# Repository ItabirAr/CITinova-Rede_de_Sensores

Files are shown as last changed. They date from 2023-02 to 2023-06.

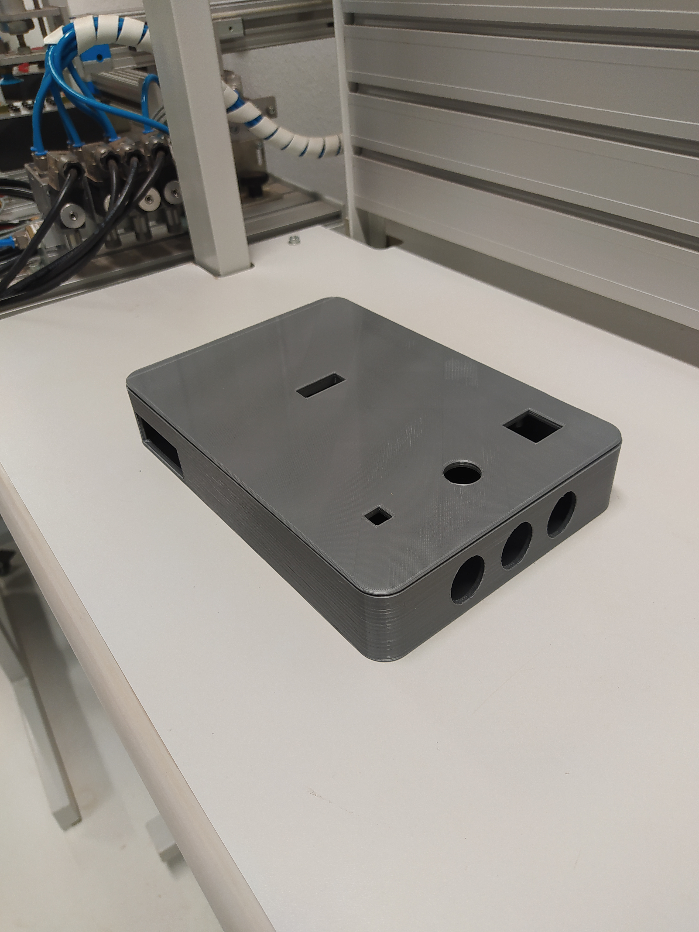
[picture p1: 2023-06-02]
CASE/Case v2/Imagens/Case_v2_impressa_5.jpg

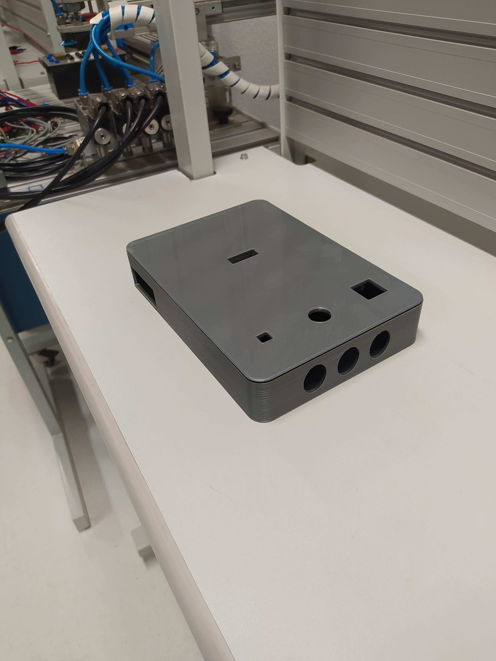
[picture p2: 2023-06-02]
CASE/Case v2/Imagens/Case_v2_impressa_4.jpg

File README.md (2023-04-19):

# Rede de sensores

O projeto Rede de sensores tem como objetivo a implementação de um protótipo capaz monitorar os principais poluentes atmosféricos de baixo custos, além de gerar um material didático que possibilite escolas e comunidades de replicar-la ou até mesmo servir de base para que possam gerar novos protótipos de monitoramento de ar.

# Monitoramento da qualidade do ar

A poluição atmosférica vem mostrando diversos impactos negativos, causando inúmeros impactos no meio ambiente (aquecimento global, degradação do meio ambiente, etc) como também está gerando graves problemas para a saúde humana.

<div align="center">

</div>

Portanto é de extrema importância o monitoramento contínuo do ar, pois são através dos dados que são criadas normas de regulamentação que colaboram para uma melhora no bem estar social e ambiental.

<div align="center">

</div>

No entanto a construção de estações de monitoramento de ar requer um alto investimento, além de a estação necessitar de manutenções rotineiras para o seu funcionamento adequado, assim gerando mais gastos.

Com isso, uma das saídas viáveis para contornar esse problema foi o uso de sensores de baixo custo.

# Sensores de baixo custo

Os sensores de baixo custo, mesmo mostrando-se inferior em relação a precisão comparados a sensores mais avançados, obtiveram êxitos em relação à eficientes para o monitoramento do ar em centros urbanos, além de demonstrar que a sua implementação é muito mais simplificada, quando comparado com modelos de monitoramentos mais avançados, além de possibilitar diversas formas flexíveis de armazenamento, sendo uma delas o armazenamento em nuvens, provando ser uma dar formas mais viáveis economicamente e extremamente eficiente para o projeto proposto, comparados a outros meios de armazenamento.

Tendo as seguintes formulações, foi se proposto no projeto, a criação de de um protótipo capaz de monitorar a qualidade do ar de baixo custo (realizando medidas de temperatura, número de partículas por milhão no ar, umidade relativa do ar, gases presentes, raios UV e etc. ) com um Arduino Uno, com armazenamento local em uma memória SD e enviadas para uma nuvem, assim possibilitando ter uma forma de armazenamento dos dados e ao mesmo tempo possibilitando o trabalho desses dados via rede.

<div align="center">

</div>

# Protótipo 

Atualmente o protótipo em desenvolvimento está sendo montado em uma protoboard, e para uma apresentação mais rápida e simplificada, foi implementado um display oled. Além dos seguintes sensores que compõem o protótipo em desenvolvimento:

<div align="center">

</div>

# Sensores 

	* MQ-135 (concentração de gases) 
	* BMP180 (Temperatura, pressão e altitude) 
	* LM35 (Temperatura)
	* UVM-30A (Raios ultravioletas) 
	* DHT11 (Temperatura e umidade relativa do ar) 
	* GY-30 (Intensidade luminosa por área) 
	* PMS5003 (Sensor de concentração de partículas)

Para mais informações em relação a cada sensor, é possível encontrar mais informações nos seguintes link: 

* <a href="https://github.com/ItabirAr/CITinova-Rede_de_Sensores/tree/main/BMP180">BMP180</a>
* <a href="https://github.com/ItabirAr/CITinova-Rede_de_Sensores/tree/main/DHT11">DHT11</a>
* <a href="https://github.com/ItabirAr/CITinova-Rede_de_Sensores/tree/main/GY30">GY30</a>
* <a href="https://github.com/ItabirAr/CITinova-Rede_de_Sensores/tree/main/LM35">LM35</a>
* <a href="https://github.com/ItabirAr/CITinova-Rede_de_Sensores/tree/main/MQ135">MQ-135</a>
* <a href="https://github.com/ItabirAr/CITinova-Rede_de_Sensores/tree/main/UVM30A">UVM-30A</a>
* <a href="https://github.com/ItabirAr/CITinova-Rede_de_Sensores/tree/main/PMS5003">PMS5003</a>

Contendo duas pastas, do qual uma delas sendo o arquivo readme.md, nela estão contidos informações básicas em relação à informações técnicas, forma de funcionamento do sensor e a forma de montagem do sensor. O outro arquivo está em um formato ino, sendo um arquivo com as programações básicas na linguagem C, para o funcionamento do sensor.

# Solicitação via Serial

A interação do protótipo Rede de Sensores com o usuário se dará via comunicação serial através do protocolo de comunicação serial RS232. O usuário poderá utilizar qualquer ferramenta que tenha essa funcionalidade, e existem várias ferramentas gratuitas disponíveis, como o PuTTY, o RealTerm e o Termite.
Além disso, é possível desenvolver uma aplicação de software dedicado para consumir as informações geradas pelo protótipo. Existem várias linguagens de programação que podem ser utilizadas para esse fim, entre elas destacam-se o Python, o Java e o C++. É importante escolher uma linguagem de programação que atenda às necessidades do projeto e que o desenvolvedor tenha conhecimento para trabalhar.

Com isso para acessar os dados armazenados na nuvem como o código elaborado e disponibilizado no projeto, existem dois comandos realizados no serial.

## getData();

No qual o comando getData() consiste em realizar uma busca completa de dados,  isto é, fazer uma impressão de todo os dados armazenados desde o seu funcionamento no serial.

<div align="center">

</div>

## getData(D1_M1_A1_D2_M2_A2)

O segundo método de impressão consiste em realizar uma busca mais específica (um intervalo de tempo mais preciso), o comando consiste em utilizar o getData(), no entanto é necessário realizar um inserção de tempo desejado, getData(D1_M1_A1_D2_M2_A2) sendo que D significa o dia, M o més e o A o ano, além de que as variáveis acompanhado com o número 1 está relacionado a data inicial de leitura e as variáveis acompanhados por 2 está relacionado a data final de leitura.

<div align="center">

</div>

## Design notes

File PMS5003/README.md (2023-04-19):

# Sensor PMS 5003

<div align="center">

</div>

Pinos   | Função | Definição
--------|--------|----------
PIN 1    | VCC    | Tensão de 5V
PIN 2    | GND    | Terra
PIN 3    | SET    | Define a tensão em 3.3V, alto nível ou suspendendo é um status normal de trabalho, enquanto baixo nível é o modo de descanso
PIN 4   | RX     | Porta serial recebendo dados / 3.3V
PIN 5   | TX     | Porta serial enviando dados / 3.3V
PIN 6   | RESET  | Reseta o sinal
PIN 7/8 | NC     |

## Descrição do Sensor
Através do espalhamento de laser dentro do cabine, há uma irradiação nas partículas presentes no interior do sensor (causando assim uma mudança nos feixes do laser em relação a condição inicial). Em seguida, tendo a alteração nos feixes do laser, os dados são coletados. Através do processamento de dados é possível obter a concentração e o tamanho das partículas no ambiente de estudo. 

<div align="center">

</div>

O PMS 5003 é um um sensor de concentração de partículas digital e universal, extremamente preciso, capaz de captar partículas de até 0.3μm. É projetado com blindagem nas 6 paredes do eletrônico para evitar interferências não desejadas. 

## Documentação

O datasheet contendo a documentação do sensor BMP180 pode ser encontrada no seguinte link: <a href="https://www.digikey.jp/htmldatasheets/production/2903006/0/0/1/pms5003-series-manual.html">Clique aqui</a>

<h1> Informações Técnicas </h1>
	
<ul>
	<li>PMS 5003</li>
	<li>Faixa de leitura de PM2,5: ±10% 100~500μ </li>
	<li>Eficiência de contagem de PM:50% para 0,3μm   98% para >=0,5μm </li>
	<li>Temperatura ideal para o funcionamento: -10 à +60°C</li>
	<li>Umidade ideal para o funcionamento: 0 à 99% de umidade relativa do ar</li>
	<li>Dimensões 50x38x21mm</li>
<ul>

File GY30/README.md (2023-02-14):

# Sensor GY30
<div align="center">

</div>

## Descrição do Sensor
Esse sensor é baseado em um semicondutor do tipo fotodiodo que, quando exposto a uma fonte de luz, absorve fótons e os converte em corrente elétrica. Portanto o sinal elétrico gerado pode ser relacionado ao nível de luminosidade do ambiente monitorado. Como o sinal gerado é muito pequeno, ele precisa ser condicionado, o que é feito através de um amplificador de sinal. Em seguida, esse sinal precisa ser preparado para ser transmitido, por isso ele passa por um conversor analógico-digital e depois por um processador que calcula o índice de luminosidade com base na quantidade de luz absorvida. Por fim, o índice de luminosidade é transmitido para ser armazenado.

<div align="center">

</div>

O sensor, fabricado por ROHM Semiconductor, foi projetado para detectar o espectro de luz visível ao olho humano com sensibilidade de pico em 560 nm, que está no espectro verde. Agama completa abrange aproximadamente 400 nm a 700 nm. O sensor funciona bem com amaioria das luzes brancas visíveis, incluindo a luz solar, incandescente, fluorescente, halógena e LED branca. Tem boa rejeição de UV e IR.
O I2C utiliza dois canais para comunicação. A diferença é que, nesse caso, um canal é de transmissão e recepção de dados e outro é para sincronização dos mesmos. Em relação aos dois canais de comunicação, temos: o canal de dados seriais, chamado de serial data (SDA); e o canal de sincronização, chamado serial clock (SCL). Simplificadamente, o Clock é um sinal que oscila entre nível alto e baixo rapidamente. Então, essa oscilação é utilizada para sincronizar os dispositivos a cada vez que o clock apresentar certo estado.

## Documentação

O datasheet contendo a documentação do sensor BMP180 pode ser encontrada no seguinte link: <a href="https://www.mouser.com/datasheet/2/348/bh1750fvi-e-186247.pdf">Clique aqui</a>

<h1> Informações Técnicas </h1>
	
<ul>
	<li>Tensão de operação 3 à 5VDC</li>
	<li>Faixa de leitura de luminosidade: 1 à 65535lx(±20%)</li>
	<li>Conexão I2C</li>
	<li>Dimensões 33x20x3mm</li>
<ul>

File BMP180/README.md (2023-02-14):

# Sensor BMP180

<div align="center">

</div>

## Descrição do Sensor
O BMP180 é composto por um sensor piezoresistivo e um sensor MEMS de temperatura. 
O sensor piezoresistivo utiliza um diafragma de material semicondutor cuja resistência varia de acordo com a pressão. Dessa forma, a intensidade da corrente que passa pelo diafragma é proporcional à força causada pela pressão. 
O sensor de temperatura é um MEMS (Sistema Microeletromecânico) que funciona a partir de uma lente de silício que reúne a radiação infravermelha em um material semicondutor cuja informação de temperatura está correlacionada com a diminuição da resistência do material. 

<div align="center">

</div>

O BMP180 mede temperatura, altitude e pressão. Porém para esse projeto serão coletados apenas os dados de temperatura e pressão fornecidos pelo sensor. O modelo é fabricado pela BOSCH Invented For Life, ou pela TEXAS INSTRUMENTS.
Utiliza-se a Comunicação Serial I2C – Inter-Integrated Circuit – a qual utiliza dois canais para comunicação: um canal para transmissão e recepção de dados (SDA) e outro a para sincronização dos dados (SCL).

## Documentação

O datasheet contendo a documentação do sensor BMP180 pode ser encontrada no seguinte link: <a href="https://cdn-shop.adafruit.com/datasheets/BST-BMP180-DS000-09.pdf">Clique aqui</a>

<h1> Informações Técnicas </h1>
	
<ul>
	<li>CI BMP180</li>
	<li>Tensão de operação 1.8 à 3.6VDC</li>
	<li>Consumo de corrente: 0.5µA</li>
	<li>Faixa de leitura de pressão: 300 à 11001hPa(+9000 à -500m)</li>
	<li>Conexão I2C</li>
	<li>Sensor de temperatura embutido: -40 à +85°C</li>
	<li>Calibrção de fábrica</li>
	<li>Dimensões 13x10mm</li>
<ul>

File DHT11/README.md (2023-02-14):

# Sensor DHT11

<div align="center">

</div>

## Descrição do Sensor
O DHT11 é composto por um sensor resistivo e um termistor NTC. 
O sensor resistivo mede a umidade pela variação da resistência de um material capaz de absorver umidade. Ao absorver vapor d‘água, a resistência do material diminui por causa do aumento da condutividade elétrica. 
Um termistor é um dispositivo elétrico cuja resistência elétrica altera drasticamente com a temperatura. Para o tipo NTC, a resistência interna reduz com o aumento da temperatura, geralmente utiliza-se uma Ponte de Wheatstone ou um Amplificador para obter uma aproximação linear. 

<div align="center">

</div>

O DH11 realiza medições de temperatura (°C) e umidade relativa do ar (%UR). Os principais fabricantes são a  UNIVERSAL-SOLDER Electronics Ltd  e a  Guangzhou Aosong Electronics Co Ltd . O sensor deve ser alimentado por fonte de tensão entre 3,0V e 5,5V.
O DTH11 transmite dados por comunicação serial Single-Wire Two-Way, o sensor possui conversor análogo digital interno de 16 bits. Após o microcontrolador enviar um sinal de inicialização, o sensor entra em modo de execução. É transmitido um sinal de 40 bits para o Arduino, em pacotes de 8 bits: o byte. Os primeiros 4 bytes são as informações de umidade e temperatura. O último byte trata-se da soma dos 32 dígitos anteriores, para verificação de autenticidade dos dados. Em seguida, o sensor entra em modo de baixo consumo e aguarda um novo sinal do Arduino.

## Documentação

O datasheet contendo a documentação do sensor DHT11 pode ser encontrada no seguinte link: <a href="https://www.mouser.com/datasheet/2/758/DHT11-Technical-Data-Sheet-Translated-Version-1143054.pdf">Clique aqui</a>

<h1> Informações Técnicas </h1>
	
<ul>
	<li>Tensão de operação 3 à 5.5VDC</li>
	<li>Consumo de corrente: 0.5 à 2.5µA</li>
	<li>Faixa de leitura de umidade: 20 à 90% (±5%) RH</li>
	<li>Faixa de leitura de temperatura: 0° à 50° (±2°) C</li>
	<li>Saída: Digital</li>
	<li>Dimensões 12x23.5x5.5mm</li>
<ul>

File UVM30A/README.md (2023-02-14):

# Sensor UVM-30A

O sensor UVM30A é utilizado para medir a intensidade de radiação ultravioleta. O codigo disponivel esta normalizado para ter como resultado a intensidade UV de acordo com o index UV, padrão internacional de medida da intensidade UV.

<div align="center">

</div>

## Descrição do Sensor
O funcionamento interno do módulo UVM30A é baseado em um fotodiodo, que é o componente responsável por converter a radiação Ultra Violeta em corrente elétrica. A luz UV incide no fotodiodo, causando a liberação de elétrons e a criação de portadores de carga geram uma corrente elétrica proporcional à intensidade da radiação UV.
A corrente gerada pelo fotodiodo é amplificada por um circuito amplificador operacional e processado por um circuito de compensação de temperatura, que corrige as variações da sensibilidade do fotodiodo com a temperatura. O circuito completo é encapsulado em uma caixa para protegê-lo contra a radiação UV e outros ambientes adversos.

<div align="center">

</div>

O UVM30A mede a intensidade de incidência dos raios ultravioletas e é fabricado pela EKT.
Através da porta analógica, o sensor é alimentado com uma tensão de operação e no terceiro terminal, sai uma tensão proporcional à incidência de luz UV.     A radiação ultravioleta (UV) é entendida como toda a radiação eletromagnética com comprimento de onda entre 200 e 400 nanômetros (nm), sendo assim o sensor emite um sinal elétrico que varia com a intensidade UV, ou seja, de acordo com o comprimento da onda.

## Documentação

O datasheet contendo a documentação do sensor UVM-30a pode ser encontrada no seguinte link: <a href="https://www.google.com/url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">Clique aqui</a>

Este sensor não necessita de nenhuma biblioteca para seu funcionamento.

## Informações Técnicas
	
<ul>
	<li>Tensão de operação: 3 à 5VDC</li>
	<li>Consumo de corrente: 0.06 à 0.1µA</li>
	<li>Tensão de saída: 0-1V (correspondente a 0-10 UV index)</li>
	<li>Leitura de onda UV na faixa de 200 à 37-nm</li>
	<li>Temperatura de trabalho: -20° à +85°C</li>
	<li>Dimensões 28x12x10mm</li>
<ul>

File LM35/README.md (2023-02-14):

# Sensor LM35

O LM35 é um sensor de temperatura linear de baixo custo, que fornece uma saída de tensão proporcional à temperatura. Ele é amplamente utilizado em sistemas de controle de temperatura devido à sua facilidade de uso e precisão.
<div align="center">

</div>

## Descrição do Sensor
O LM35 é composto por um elemento termoelétrico, geralmente feito de silício, protegido por uma caixa metálica, que também funciona como um terminal de referência para a medição de tensão. Usa o princípio básico de um diodo, onde à medida que a temperatura aumenta em comparação com a temperatura de referência, a tensão através de um diodo aumenta a uma taxa conhecida (10mV/°C). Ao amplificar precisamente a mudança de tensão, gera um sinal analógico diretamente proporcional à diferença de temperatura.

<div align="center">

</div>

O LM35 mede temperatura ambiente e é fabricado pela TEXAS INSTRUMENTS.
Comunica-se por Porta Serial Analógica, que entrega uma tensão proporcional a temperatura, ademais há outros 2 pinos no sensor, estes de alimentação Vcc e GND

## Documentação

O datasheet contendo a documentação do sensor LM35 pode ser encontrada no seguinte link: <a href="https://www.google.com/url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">Clique aqui</a>

Este sensor nao necessita de biblioteca para seu funcionamento 

<h2> Informações Técnicas </h2>
	
<ul>
	<li>Tensão de operação 4 à 30VDC</li>
	<li>Consumo de corrente máxima: 60µA</li>
	<li>Faixa de leitura de temperatura: -55° à 150° (±0.5°) C</li>
<ul>

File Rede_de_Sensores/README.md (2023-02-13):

# Integração dos Sensores

<div align="center">

</div>

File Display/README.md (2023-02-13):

# Display

O display OLED SSD1306 é um tipo de display de cristal líquido orgânico de alta qualidade, que é utilizado em muitos projetos de eletrônica e robótica. É caracterizado por sua alta resolução, baixo consumo de energia e excelente contraste, tornando-o uma escolha popular para aplicações de visualização de dados.

<div align="center">

</div>

## Descrição do display

O SSD1306 é controlado por um controlador de display OLED integrado, que é responsável por gerenciar todas as operações de exibição, incluindo a renderização de texto e gráficos. O display é alimentado por meio de uma conexão serial I2C, e pode ser facilmente integrado a microcontroladores como o Arduino, Raspberry Pi ou outros dispositivos similares.

O SSD1306 é altamente personalizável, permitindo aos usuários definir o tamanho e o formato da tela, bem como ajustar as configurações de contraste, brilho e outras opções de visualização. Além disso, ele suporta a exibição de texto e gráficos, incluindo fontes personalizadas, gráficos vetoriais e imagens bitmap.

## Documentação

O datasheet contendo a documentação do display pode ser encontrado no seguinte link: <a href="https://datasheethub.com/wp-content/uploads/2022/08/SSD1306.pdf">Clique aqui</a> 

Para ter acesso as configurações de personalização do display é utilizada as seguintes bibliotecas:
<ul>
	<li>Adafruit_SSD1306 disponivel em:  <a href="https://www.arduinolibraries.info/libraries/adafruit-ssd1306">Clique aqui</a> </li>
	<li>Adafruit_GFX disponivel em: <a href="https://www.arduinolibraries.info/libraries/adafruit-gfx-library">Clique aqui</a> </li>
<ul>

## Informações tecnicas
  
<ul>
	<li>Tamanho da tela: 0.96 polegadas</li>
	<li>Resolução: 128x64 pixels</li>
	<li>Interface de comunicação I2C</li>
	<li>Alimentação: Vdc de 3.3V á 5V e consome cerca de 60mA em operação</li>
<ul>

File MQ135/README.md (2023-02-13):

# Sensor MQ-135

O sensor MQ135 será utilizado para medir a concentração de gás CO2. Este sensor é projetado especificamente para detectar gases poluentes, como dióxido de carbono, e fornecer uma leitura precisa da concentração de gás no ar. 

<div align="center">

</div>

## Descrição do Sensor
Trata-se de um sensor semicondutor do tipo MOS (metal oxide semiconductor). O material sensível do sensor é o SnO2 (óxido de estanho), que possui baixa condutividade quando exposta ao ar limpo. À medida que surgem algum tipos de gases, sua condutividade aumenta com a concentração desses gases. Colocando-se então esse material entre dois eletrodos e em série com uma resistência conhecida e, aplicando-se uma tensão elétrica constante sobre esse conjunto, obtém-se na saída uma tensão elétrica proporcional à concentração de gases. Quanto maior a concentração de gás, maior será a tensão de saída. O sensor tem uma temperatura de funcionamento padrão que é fornecida por um eletrodo de aquecimento

<div align="center">

</div>

O sensor MQ-135 é capaz de detectar gases tóxicos no ar, podendo detectar concentrações entre 10 e 300 ppm (partes por milhão) de amônia e álcool e entre 10 e 1000 ppm de benzeno no ar. A sua sensibilidade é ajustada por um trimpot acoplado a sua placa. Em concentrações normais do gás, a saída digital do sensor permanece desligada, quando o ponto de ajuste (setpoint) é ultrapassado, a saída digital é ligada permanecendo em nível alto. Além da saída digital, o sensor possui saída analógica, possibilitando a leitura da concentração medida de gases no ar com precisão. Sempre que alimentado, o LED de alimentação permanecerá aceso, já o LED da saída digital é acionado quando o valor lido pelo sensor superar o ponto de ajuste. O trimpot é o variador da sensibilidade na qual aciona a saída digital.

## Documentação
O datasheet contendo a documentação do sensor MQ-135 pode ser encontrado no seguinte link: <a href="https://pdf1.alldatasheet.com/datasheet-pdf/view/1307647/WINSEN/MQ135.html">Clique aqui</a> 

Para o sensor medir concentrações de CO2 é importante atentar a algumas configurações que devem ser realizadas previamente, as informações e procedimentos pode ser encontrados no seguinte link: <a href="https://circuitdigest.com/microcontroller-projects/interfacing-mq135-gas-sensor-with-arduino-to-measure-co2-levels-in-ppm">Clique aqui</a> 

A biblioteca utilizada no código pode ser encontrada no seguinte link: <a href="https://www.arduinolibraries.info/libraries/mq135">Clique aqui</a> 

## Informações tecnicas
<ul>
	<li>Tensão de operação: 5VDC</li>
	<li>Faixa de detecção amônia: 10ppm à 300ppm</li>
	<li>Faixa de detecção benzeno: 10ppm à 1000ppm</li>
	<li>Faixa de detecção álcool: 10ppm à 300ppm</li>
	<li>Saídas: Digital e analógica</li>
	<li>Dimensões 40x25x22mm</li>
<ul>

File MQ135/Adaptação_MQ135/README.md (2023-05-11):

# MQ-135

Inicialmente o sensor MQ-135 foi projetado para detectar uma alta variedade de gases nocivos (NH3, NOx, álcool, benzeno, fumaça e CO2). No entanto, para atender aos interesses do projeto, foram feitas adaptações para que o sensor leia apenas quantidades de CO2 presente no ar.

Sabendo-se que os valores lidos pelo sensor é uma conversão do valor lido na tensão entregue na carga resistiva, sendo que a variação da tensão depende do valor da carga resistiva presente no sensor. É de extrema importância que a resistência presente no sensor tenha um valor expressivo para que o cálculo na leitura possa ser preciso.

# Procedimento

Inicialmente para iniciar a adaptação do sensor MQ-135 para a leitura de CO2, é necessário a troca do resistor  Rs de 1K ohm para uma resistência de 22k ohm, pois a leitura de CO2 é mais sensível que outros gases, resultando em uma variação de tensão menor caso o Rs seja um valor muito baixo.

<div align="center">

</div>

Fazendo se a troca é possível observar com uma maior variação, pois a tensão lida é feita através do cálculo da divisão de tensão entre Rs e a resistência lida no material SnO2.

Tendo feita a seguinte troca, o restante das adaptações a partir serão as mudanças feitas através de softwares. Os dados necessários para as alterações inicialmente e descobrir o valor da resistência resultante do material SnO2 em ar limpo. Para medir tais valores inicialmente é necessário manter o sensor ligado durante um período de 24 horas e após isso utiliza-se o seguinte código, o código retornará um valor para o R0 no serial.

```
#include "MQ135.h"
configuração nula (){
Serial.begin (9600);
}
loop void() {
Sensor de gás MQ135 = MQ135(A0); // Conecta o sensor ao pino A0
float rzero = gasSensor.getRZero();
Serial.println (rzero);
atraso(1000);
}
```
Tendo o valor medido, é preciso atualizar os dados da biblioteca, e para isso basta seguir o seguinte caminho: Documentos > Arduino > bibliotecas > pasta MQ135 e abra o arquivo MQ135.h e altere os valores RLOAD e RZERO.

<div align="center">

</div>

obs: atualizar também o valor de ATMOCO2, que é um valor médio de CO2 presente na atmosfera terrestre, um valor que pode ser encontrado na internet (Para julho de 2022 foi encontrado um valor de 414.47).

<div align="center">

</div>

# Referência

Measuring CO2 concentration in air using Arduino and MQ-135 sensor. Disponível em: <https://circuitdigest.com/microcontroller-projects/interfacing-mq135-gas-sensor-with-arduino-to-measure-co2-levels-in-ppm>. Acesso em: 30 abr. 2023.

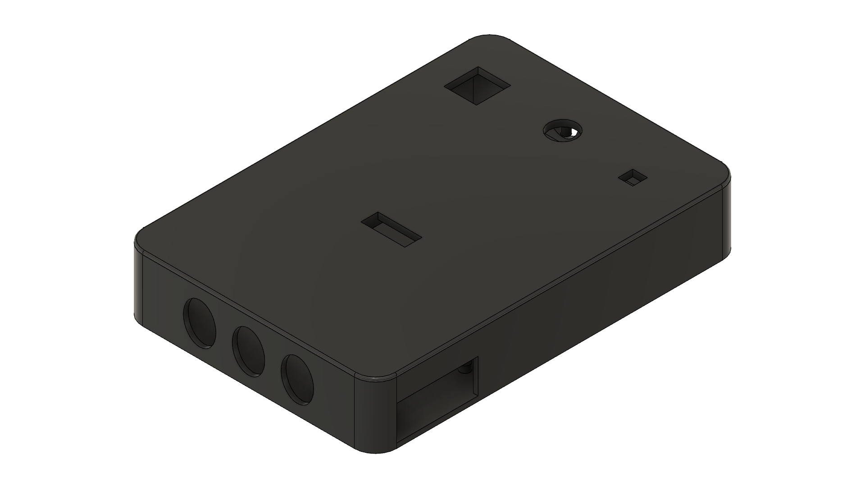
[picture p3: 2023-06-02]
CASE/Case v2/Imagens/Case_v2_fechada_sem_renderizar.png

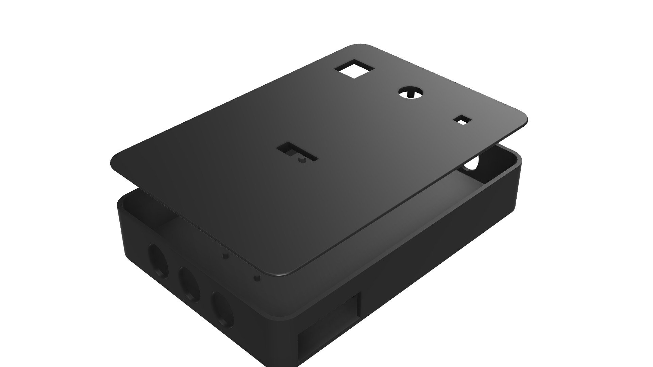
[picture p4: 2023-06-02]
CASE/Case v2/Imagens/Case_v2_aberta.png

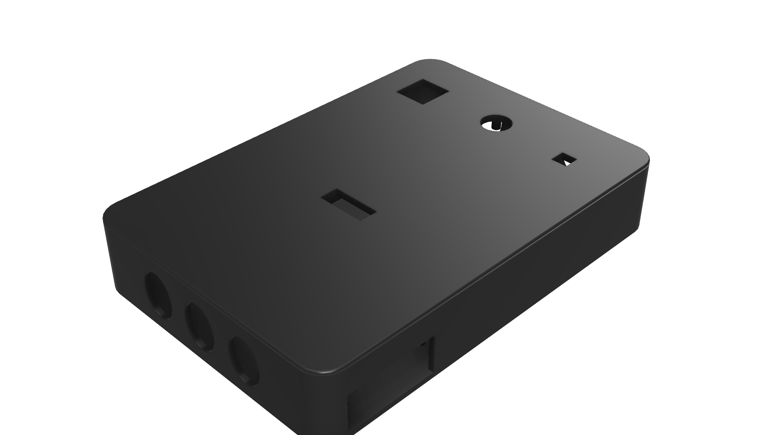
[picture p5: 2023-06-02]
CASE/Case v2/Imagens/Case_v2_fechada.png

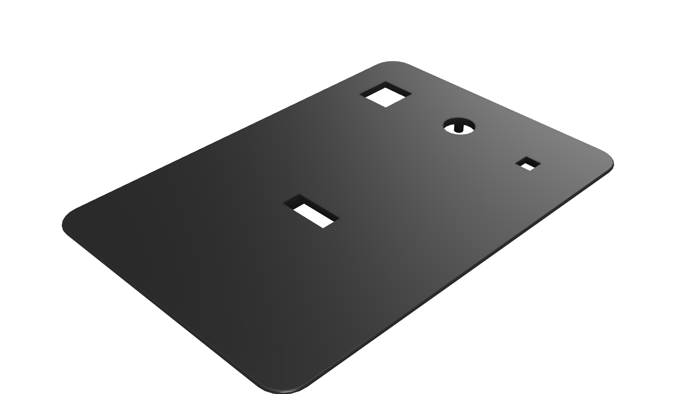
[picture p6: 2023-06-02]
CASE/Case v2/Imagens/Case_v2_tampa.png

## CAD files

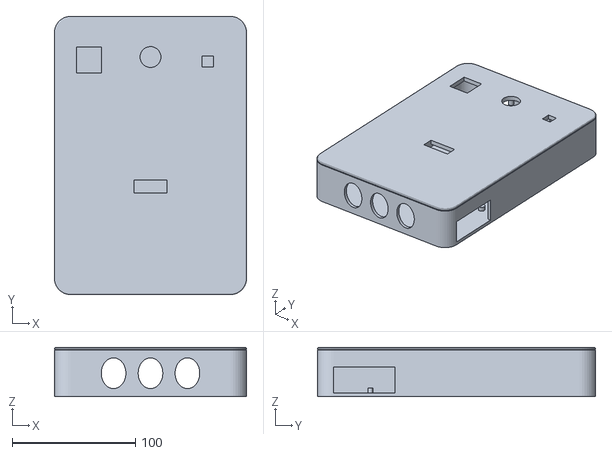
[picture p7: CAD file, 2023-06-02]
CASE/Case v2/Modelagem/Case_v2.stl
156.0 x 226.0 x 40.0

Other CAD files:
CASE/Case v1/Modelagem/Case_V1.f3d
CASE/Case v2/Modelagem/Case_v2.f3d

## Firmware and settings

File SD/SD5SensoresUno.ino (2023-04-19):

// Integração Módulo SD com BMP180, MQ135, UVM30A, DHT11, GY30
#include <SD.h> // Biblioteca para comunicação com cartão SD
#include <Adafruit_BMP085.h> //biblioteca do sensor BMP180
#include <MQ135.h> //biblioteca do sensor MQ135
#include <DHT.h> //biblioteca do sensor DHT11
#include <Wire.h> // bibilioteca de comunicação entre dispositivos por protocolo I2C
#include <BH1750.h> //biblioteca do sensor GY30

File dataFile; // Objeto que representa o arquivo de dados
const int chipSelect = 10; // Pino para seleção do cartão SD
unsigned long lastSaveTime = 0; // Último momento em que os dados foram salvos no cartão SD
unsigned long lastReadTime = 0; // Último momento em que os sensores foram lidos
String fileName = "bmp.txt";; // Nome do arquivo
char valueSerial;

// Buffers para armazenamento de dados
int bufferIndex = 0; // Índice atual do buffer
const int bufferSize = 10; // Tamanho do buffer de dados
String dataString = ""; // Cria uma string
// BMP180 (5V) SDA, SCL
Adafruit_BMP085 bmp; // define bmp como objeto do tipo Adafruit_BMP085 (I2C)
float bufferTemperaturaBMP[bufferSize]; // vetor para os dados lidos de temperatura
int bufferPressaoBMP[bufferSize]; // vetor para os dados lidos de pressão

long int Millis[bufferSize];


// MQ135 (5V) A2
#define pinoMQ A2
MQ135 mq = MQ135(pinoMQ);
float bufferCo2MQ[bufferSize]; // vetor para os dados lidos de CO2
// UVM30A (5V) A0
#define pinoUVM A0
int bufferUltravioletaUVM[bufferSize];   // declara um vetor para a resposta do sensor
// DHT11 (5V) A1
#define pinoDHT A1 // pino usado para conexão
#define modeloDHT DHT11 // modelo do sensor
DHT dht(pinoDHT, modeloDHT); // define dht como objeto do tipo DHT
float bufferTemperaturaDHT[bufferSize]; // vetor para os dados lidos de temperatura
float bufferUmidadeDHT[bufferSize]; // vetor para os dados lidos de umidade
// GY30 (5V) SDA, SLC
BH1750 gy; // define gy como objeto do tipo BH1750
float bufferIluminanciaGY[bufferSize]; // vetor para os dados lidos de iluminãncia (intensidade luminosa por área) 

void setup() {
  // Inicia comunicação serial com taxa de 9600 bps
  Serial.begin(9600); 
  Serial.println("Inicializando componentes...");
  
  // Configura pino de seleção do cartão SD como saída
  pinMode(chipSelect, OUTPUT);
  SD.begin(chipSelect);
  /* Inicializa cartão SD
  if (!SD.begin(chipSelect)) {
    Serial.println("Erro ao inicializar o cartão SD! Verifique as conexões.");
    return;
  }*/
  
  // Inicialização do BMP180
  if (!bmp.begin()) { 
    // se o sensor não for inicializado, apresenta a mensagem:
    Serial.println("Sensor BMP180 não foi identificado! Verifique as conexões.");
    while (1) {
      // em loop (repetições) até o sensor inicializar
    }
  }
  // Inicialização do DHT11
  dht.begin(); //inicializa o sensor DHT11
  // Inicialização do GY30
  Wire.begin(); //inicializa o I2C BUS
  gy.begin(); //inicializa o sensor GY30
  // Testa se os sensores DHT11 e GY30 estão recebendo dados numéricos
  testeDHT_GY();
  
  // Deleta um arquivo de mesmo nome caso já exista
  if(SD.exists(fileName)) {
    SD.remove(fileName);
  }
  // Cria arquivo de dados
  if (!SD.exists(fileName)) {
    dataFile = SD.open(fileName, FILE_WRITE);
    dataFile.close();
  }
  
  // Abre o arquivo e escreve legenda dos dados
  dataFile = SD.open(fileName, FILE_WRITE);
  dataString = "Tempo[ms], Conc.CO2[ppm], IndiceUV, Temperatura[°C], UmidadeRelativa[%UR], Iluminância[lux]";
  dataFile.print(dataString);
  dataFile.close();
  
  lastSaveTime = millis(); // Inicializa variável de último momento de salvamento de dados
  
 
  // Inicializa buffers de dados com valor 0
  for (int i = 0; i < bufferSize; i++) {
    Millis[i] = 0;
    bufferTemperaturaBMP[i] = 0;
    bufferPressaoBMP[i] = 0;
    bufferCo2MQ[i] = 0;
    bufferUltravioletaUVM[i] = 0;
    bufferTemperaturaDHT[i] = 0;
    bufferUmidadeDHT[i] = 0;
    bufferIluminanciaGY[i] = 0;
  }
  
  Serial.println("Programa iniciado."); // Imprime mensagem de início do programa
}


void loop() {
  unsigned long currentTime = millis(); // Obtém momento atual

  // Realiza leitura dos sensores a cada 1 segundo
  if (currentTime - lastReadTime >= 1000) {
    Millis[bufferIndex]=millis();
    
    bufferTemperaturaBMP[bufferIndex] = bmp.readTemperature(); // temperatura informada pelo sensor
    bufferPressaoBMP[bufferIndex] = bmp.readPressure(); // pressão informada pelo sensor
    bufferCo2MQ[bufferIndex] = mq.getPPM(); // concentração de CO2 informada pelo sensor
    bufferUltravioletaUVM[bufferIndex] = medicaoUVM(); // atribui o valor do índice de radiação uv por meio de uma função
    bufferTemperaturaDHT[bufferIndex] = dht.readTemperature();  // temperatura informada pelo sensor
    bufferUmidadeDHT[bufferIndex] = dht.readHumidity(); // umidade informada pelo sensor
    bufferIluminanciaGY[bufferIndex] = gy.readLightLevel(); // iluminância informada pelo sensor
    bufferIndex++; // Incrementa índice do buffer

    // Salva dados no cartão SD quando o buffer estiver cheio
    if (bufferIndex == bufferSize) {
        Serial.println("Tempo[ms], Temp_BMP180[°C], Pressao[Pa], Conc.CO2_MQ135[ppm], Temp_LM35[°C], IndiceUV, Temp_DHT11[°C], UmidadeRelelativa[%UR], Iluminância[lux]");
      monitorSerial();
      saveData();
      testeDHT_GY();
      bufferIndex = 0;
    }

    // Atualiza último momento de leitura dos sensores
    lastReadTime = currentTime;
  }
  if (Serial.available()) { //verifica se entrou com requisição de dados no serial
    valueSerial = Serial.read();
    if(valueSerial == '1'){ //comando 1 retorna todos os dados
      requisicaoGetData();
   }
    if(valueSerial == '2'){  // comando 2 retorna dados de um intervalo
      requisicaoGetInterval();
    }
  }
}

// Função do UVM30A
int medicaoUVM(){
  float leituraSensorUVM = analogRead(pinoUVM)*(5000 / 1023); // atribui nível de tensão de saída do sensor a uma variavel
  if (leituraSensorUVM >= 0 && leituraSensorUVM < 50) {
    return 0;
  } else if (leituraSensorUVM >= 50 && leituraSensorUVM < 227) {
    return 1;
  } else if (leituraSensorUVM >= 227 && leituraSensorUVM < 318) {
    return 2;
  } else if (leituraSensorUVM >= 318 && leituraSensorUVM < 408) {
    return 3;
  } else if (leituraSensorUVM >= 408 && leituraSensorUVM < 503) {
    return 4;
  } else if (leituraSensorUVM >= 503 && leituraSensorUVM < 606) {
    return 5;
  } else if (leituraSensorUVM >= 606 && leituraSensorUVM < 698) {
    return 6;
  } else if (leituraSensorUVM >= 698 && leituraSensorUVM < 795) {
    return 7;
  } else if (leituraSensorUVM >= 795 && leituraSensorUVM < 881) {
    return 8;
  } else if (leituraSensorUVM >= 881 && leituraSensorUVM < 976) {
    return 9;
  } else if (leituraSensorUVM <= 976 && leituraSensorUVM < 1079) {
    return 10;
  } else if (leituraSensorUVM > 1079) {
    return 11;
  }
}



void testeDHT_GY() {
  float temperaturaDHT = dht.readTemperature();  // temperatura informada pelo sensor
  float umidadeDHT = dht.readHumidity(); // umidade informada pelo sensor
  if (isnan(temperaturaDHT) || isnan(umidadeDHT)) { 
    //se a for atribuido um valor não numérico, indica erro de leitura no DHT11
    Serial.println("Falha de leitura do DHT11! Verifique as conexões.");
  }
  float iluminanciaGY = gy.readLightLevel(); // iluminância informada pelo sensor
  if (isnan(iluminanciaGY)) { 
    //se a for atribuido um valor não numérico, indica erro de leitura no GY30
    Serial.println("Falha de leitura do GY30! Verifique as conexões.");
  }
}



void saveData() {
  // Obtém momento atual
  unsigned long currentTime = millis();

  // Verifica se já passaram 10 segundos desde o último salvamento de dados
  if (currentTime - lastSaveTime < 10000) {
    return;
  }

  // Atualiza o lastSaveTime com o currentTime
  lastSaveTime = currentTime;

  // Atribui os dados do buffer
  for (int i = 0; i < bufferSize; i++) {
    dataString += String(currentTime - ((bufferSize - 1 - i) * 1000)) + ", ";  
    dataString += String(bufferTemperaturaBMP[i]) + ", ";
    dataString += String(bufferPressaoBMP[i]) + ", ";
    dataString += String(bufferCo2MQ[i]) + ", ";
    dataString += String(bufferUltravioletaUVM[i]) + ", ";
    dataString += String(bufferTemperaturaDHT[i]) + ", ";
    dataString += String(bufferUmidadeDHT[i]) + ", ";
    dataString += String(bufferIluminanciaGY[i]) + "\n";
  }

  // Abre o arquivo para escrita e escreve os dados
  dataFile = SD.open(fileName, FILE_WRITE);
  dataFile.print(dataString);
  dataFile.close();

  Serial.println("Dados salvos.");
}

//Função de requisição de todos os dados do sd
void requisicaoGetData(){
  dataFile = SD.open("BMP.txt");
  if(dataFile){
    while(dataFile.available()){
      Serial.write(dataFile.read());
    }
  }
}

//requisição de um intervalo de dados do SD
void requisicaoGetInterval(){
  unsigned long start_time = Serial.parseInt();
  unsigned long end_time = Serial.parseInt();
  Serial.print("Tempo inicial: ");
  Serial.println(start_time);
  Serial.print("Tempo final: ");
  Serial.println(end_time);

  dataFile = SD.open("BMP.txt");
  if(dataFile){
    while(dataFile.available()){
      String request = dataFile.readStringUntil('\n');
      String timeStr = request.substring(0, request.indexOf(','));
      unsigned long time = timeStr.toInt();
      if (time >= start_time && time <= end_time) {
        String valueStr = request.substring(request.indexOf(',') + 1);
        Serial.print("Tempo: ");
        Serial.print(time);
        Serial.print(" | Valor: ");
        Serial.println(valueStr);
      }
    }
  }
}

// ** MONITOR SERIAL **
void monitorSerial() { // função para imprimir  os resultados obtidos
  for(int j = 0; j < bufferSize; j++) {
    
    Serial.print(Millis[j]); //BMP180
    Serial.print(", ");
    Serial.print(bufferTemperaturaBMP[j]); //BMP180
    Serial.print(", ");
    Serial.print(bufferPressaoBMP[j]);   
    Serial.print(", ");
    Serial.print(bufferCo2MQ[j]); //MQ135   
    Serial.print(", ");
    Serial.print(bufferUltravioletaUVM[j]); //UVM3OA   
    Serial.print(", ");
    Serial.print(bufferTemperaturaDHT[j]); //DHT11
    Serial.print(", ");
    Serial.print(bufferUmidadeDHT[j]);   
    Serial.print(", ");
    Serial.println(bufferIluminanciaGY[j]); //GY30
  }
}

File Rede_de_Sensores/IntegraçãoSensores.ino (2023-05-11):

// Integração dos sensores BMP180, MQ135, LM35, UVM30A, DHT11, GY30 com interrupção
#include <TimerOne.h> //biblioteca do temporizador interno do arduino
#include <Adafruit_BMP085.h> //biblioteca do sensor BMP180
#include <MQ135.h> //biblioteca do sensor MQ135
#include <DHT.h> //biblioteca do sensor DHT11
#include <Wire.h> //bibilioteca de comunicação entre dispositivos por protocolo I2C
#include <BH1750.h> //biblioteca do sensor GY30

bool flag = false; // variável auxiliar para indicar a contagem de tempo
int p = 0; // variável auxiliar de posição dos vetores
const int tamanhoBuffer = 10; // tamanho do vetor
long bufferTempo[tamanhoBuffer]; // vetor com os dados de tempo

// ** VARIAVEIS BMP180 ** (3,3V) SDA-A4, SCL-A5
Adafruit_BMP085 bmp; // define bmp como objeto do tipo Adafruit_BMP085 (I2C)
float bufferTemperaturaBMP[tamanhoBuffer]; // vetor para os dados lidos de temperatura
int bufferPressaoBMP[tamanhoBuffer]; // vetor para os dados lidos de pressão

// ** VARIAVEIS MQ135 ** (5V) A0 
#define pinoMQ A2
MQ135 mq = MQ135(pinoMQ);
float bufferCo2MQ[tamanhoBuffer]; // vetor para os dados lidos de CO2

// ** VARIAVEIS LM35 ** (5V) A2
#define pinoLM A4
float bufferTemperaturaLM[tamanhoBuffer];  //declara um vetor para resposta do sensor

// ** VARIAVEIS UVM30A ** (3,3V ou 5V) A1
#define pinoUVM A0
int bufferUltravioletaUVM[tamanhoBuffer];   // declara um vetor para a resposta do sensor

// ** VARIAVEIS DHT11 ** (3,3V ou 5V) A3
#define pinoDHT A1 // pino usado para conexão
#define modeloDHT DHT11 // modelo do sensor
DHT dht(pinoDHT, modeloDHT); // define dht como objeto do tipo DHT
float bufferTemperaturaDHT[tamanhoBuffer]; // vetor para os dados lidos de temperatura
float bufferUmidadeDHT[tamanhoBuffer]; // vetor para os dados lidos de umidade

// ** VARIAVEIS GY30 ** (3,3V ou 5V) SDA, SLC
BH1750 gy; // define gy como objeto do tipo BH1750
float bufferIluminanciaGY[tamanhoBuffer]; // vetor para os dados lidos de iluminãncia (intensidade luminosa por área) 

void setup() {
// inicializa monitor serial
  Serial.begin(9600); 
// ** INICIALIZA BMP180 **
  if (!bmp.begin()) { 
    //se o sensor não for inicializado, apresenta a mensagem:
    Serial.println("Sensor BMP180 não foi identificado! Verifique as conexões.");
    while (1) {  //em loop (repetições) até o sensor inicializar
    } 
  }
// ** INICIALIZA DHT11 **
  dht.begin(); //inicializa o sensor DHT11
// ** INICIALIZA GY30 **
  gy.begin(); //inicializa o sensor GY30
// temporizador interno do arduino
  Timer1.initialize(1000000); // 1s
  Timer1.attachInterrupt(callback);
// *** variáveis medidas e unidades (lux = lm/m²)
  Serial.println("Tempo[ms], Temp_BMP180[°C], Pressao[Pa], Conc.CO2_MQ135[ppm], Temp_LM35[°C], IndiceUV, Temp_DHT11[°C], UmidadeRelelativa[%UR], Iluminância[lux]");
}

void callback(){
  flag = true;
}

void loop(){   
  if(flag){
    bufferTempo[p] = millis(); // milissegundos transcorridos desde que o Arduino foi ligado
    medicaoBMP();
    medicaoMQ();
    medicaoTemperaturaLM();
    bufferUltravioletaUVM[p] = medicaoUVM(); // atribui o valor do índice de radiação uv
    medicaoDHT();
    medicaoGY();
    p++;
    if (p == tamanhoBuffer-1) {
      monitorSerial(); // função que mostra os dados salvos nos vetores
      p = 0; // retorna à posição inicial dos vetores para salvar novos dados
    }
    flag = false;
  }
}



// ** FUNÇÃO BMP180 **
void medicaoBMP() {
  bufferTemperaturaBMP[p] = bmp.readTemperature(); // temperatura informada pelo sensor
  bufferPressaoBMP[p] = bmp.readPressure(); // pressão informada pelo sensor
}

// ** FUNÇÃO MQ135 **
void medicaoMQ(){     
  bufferCo2MQ[p] = mq.getPPM(); // concentração de CO2 informada pelo sensor
}

// ** FUNÇÃO LM35 **
void medicaoTemperaturaLM(){
  bufferTemperaturaLM[p] = (float(analogRead(pinoLM))*5/(1023))/0.01; // temperatura informada pelo sensor
}

// ** FUNÇÃO UVM30A **
int medicaoUVM(){
  float leituraSensorUVM = analogRead(pinoUVM)* (5000 / 1023); // atribui o nível de tensão na saída do sensor a uma variavel
  if (leituraSensorUVM >= 0 && leituraSensorUVM < 50) {
    return 0;
  } else if (leituraSensorUVM >= 50 && leituraSensorUVM < 227) {
    return 1;
  } else if (leituraSensorUVM >= 227 && leituraSensorUVM < 318) {
    return 2;
  } else if (leituraSensorUVM >= 318 && leituraSensorUVM < 408) {
    return 3;
  } else if (leituraSensorUVM >= 408 && leituraSensorUVM < 503) {
    return 4;
  } else if (leituraSensorUVM >= 503 && leituraSensorUVM < 606) {
    return 5;
  } else if (leituraSensorUVM >= 606 && leituraSensorUVM < 698) {
    return 6;
  } else if (leituraSensorUVM >= 698 && leituraSensorUVM < 795) {
    return 7;
  } else if (leituraSensorUVM >= 795 && leituraSensorUVM < 881) {
    return 8;
  } else if (leituraSensorUVM >= 881 && leituraSensorUVM < 976) {
    return 9;
  } else if (leituraSensorUVM <= 976 && leituraSensorUVM < 1079) {
    return 10;
  } else if (leituraSensorUVM > 1079) {
    return 11;
  }
}

// ** FUNÇÃO DHT11 ** (o sensor possui atraso de até 2s)
void medicaoDHT() {
  bufferTemperaturaDHT[p] = dht.readTemperature();  // temperatura informada pelo sensor
  bufferUmidadeDHT[p] = dht.readHumidity(); // umidade informada pelo sensor
  //se a for atribuido um valor não numérico, indica erro de leitura no DHT11
  if (isnan(bufferTemperaturaDHT[p]) || isnan(bufferUmidadeDHT[p])) { 
    Serial.println("Falha de leitura do DHT11");
  } 
}

// ** FUNÇÃO GY30 **
void medicaoGY(){
  bufferIluminanciaGY[p] = gy.readLightLevel(); // iluminância informada pelo sensor
  //se a for atribuido um valor não numérico, indica erro de leitura no GY30
  if (isnan(bufferIluminanciaGY[p])) { 
    Serial.println("Falha de leitura do GY30");
  } 
}

// ** MONITOR SERIAL **
void monitorSerial() { // função para imprimir  os resultados obtidos
  for(int j = 0; j < tamanhoBuffer - 1; j++) {
    Serial.print(bufferTempo[j]); //Tempo
    Serial.print(", ");
    Serial.print(bufferTemperaturaBMP[j]); //BMP180
    Serial.print(", ");
    Serial.print(bufferPressaoBMP[j]);   
    Serial.print(", ");
    Serial.print(bufferCo2MQ[j]); //MQ135   
    Serial.print(", ");
    Serial.print(bufferTemperaturaLM[j]); //LM35   
    Serial.print(", ");
    Serial.print(bufferUltravioletaUVM[j]); //UVM3OA   
    Serial.print(", ");
    Serial.print(bufferTemperaturaDHT[j]); //DHT11
    Serial.print(", ");
    Serial.print(bufferUmidadeDHT[j]);   
    Serial.print(", ");
    Serial.println(bufferIluminanciaGY[j]); //GY30
  }
}

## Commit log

2023-02-09 novas pastas para cada sensor
    Neste commit foram criadas uma pasta para cada sensor utilizado no projeto
2023-02-09 Atualização das imagens
    Neste commit foram atualizadas as imagens de cada sensor no arquivo README
2023-02-09 Remoção dos códigos
    Foram removidos todos os códigos utilizados de exemplo, para que o novo seja inserido em seguida.
2023-02-09 Adição de todos os códigos
    Neste commit foram adicionados todos os códigos de cada sensor
2023-02-09 Adição de informações
    atualização no read do sensor BMP180
2023-02-09 Atualização dos sensores
    foram adicionados dados dos sensores LM35, GY30 e BMP180
2023-02-09 atualização no README
    alteração nos dados do readme do sensor MQ135 e DHT11
2023-04-19 Codigo
    Criado uma pasta para o código do sensor e a remoção do mesmo no readme.md
2023-04-19 Update README.md
    Foi adicionado uma tabela detalhando os pinos do sensor
